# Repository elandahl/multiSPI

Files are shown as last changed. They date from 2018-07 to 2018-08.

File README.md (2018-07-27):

# multiSPI
Multiple SPI Devices on a Raspberry Pi

## Description:

Circuit diagram and software to use multiple (> 2) SPI devices on a Raspberry Pi.  This approach uses a shift register to address a demultiplexer which in turn routes up to eight chip selects.  All devices share the same MISO, MOSI, and SCLK.  The Raspberry Pi chip select CE0 is used for SPI communication to the selected device, whereas chip select CE1 is used for latching the shift register.  The particular SPI devices used in this design for demonstration purposes are four 10 bit, 4 differential channel MCP3008 Analog-to-Digital Converters.  Differential voltage measurement is implemented, although the 4 differential measurements could be replaced with eight single inputs.  Another four SPI devices could be added, and this could be further extended with a second demultiplexer to 16 devices.  An additional shft register could be added after the first for essentially unlimited extension to arbitrary numbers of SPI devices.  This same approach could be extended to other platforms such as a microcontroller.

## Author:

Eric Landahl, elandahl@gmail.com

## Acknowledgements:

Motivation from C.D. Landahl

Concept from Ellie Martin-Eberhardt

Requires use of the [C library for Broadcom BCM 2835 as used in Raspberry Pi](http://www.airspayce.com/mikem/bcm2835/index.html) by Mike McCauley.  The code here is based closely on the bcm2835 example file `spin.c`.

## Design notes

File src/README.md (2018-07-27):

# Directory of source files for multiSPI
## Installation
1. Obtain and install the [bcm2835 library](http://www.airspayce.com/mikem/bcm2835/index.html)
2. Download `MCP3008read.c` and compile with the command `gcc -o MCP3008read MCP3008read.c -l bcm2835`
3. Download `SPIselect.c` and compile with the command `gcc -o SPIselect SPIselect.c -l bcm2835`
## Usage
To select an SPI device:  `sudo ./SPIselect` *num*
  
where *num* is the address 0 - F

For instance, `sudo ./SPIselect 1` should return the statement `Device 1 has been selected`.

To read 4 differential voltages of the selected MCP3008 ADC:  `./MCP3008read`

This will return the hexadecimal readings for each differential pair; see MCP3008 datasheet for details on how to convert this output to a voltage.

Note that the use of `sudo` may not be required in more recent versions of Raspbian. Also note that depending on the Raspbian version, the SPI may need to be configured using `sudo raspi-config`.

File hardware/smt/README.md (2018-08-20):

Surface Mount design for multiSPI

multiple SPI (> 2) SPI devices on Raspberry Pi. In this case, 4x MCP3008 ADCs. 

OSH Park fabrication in process:  https://oshpark.com/shared_projects/mubjyDKl

This version uses surface mount components and has extra outputs (shift register, CEs, and SPI).s

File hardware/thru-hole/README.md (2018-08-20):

# Hardware design files for multiSPI test board

## Contents
Schematic prepared in EAGLE 9.1.0, and using DIP format comonents

Available as .png, .pdf, and EAGLE .sch files

PCB files are now also attached as .brd and well as an image as multiSPI2.pdf

First PCB has been ordered from OSH Park!  [https://oshpark.com/shared_projects/Ye1AAnSY](https://oshpark.com/shared_projects/Ye1AAnSY)

## Hardware used for tests

1. Raspberry Pi Model 3B running Raspbian GNU/Linux 8.0 (jessie)
2. Canakit cobbler breakout 
3. Full size solderless breadboard
4. Shift Register: SN74HC595N
5. Demultiplexer: T74LS138B1
6. ADC (QTY = 2 tested, QTY = 4 in circuit diagram): MCP3008
7. Pullup resistors on multi-chip select lines: (QTY = 2 or 4) approximately 100 kOhm

## Notes
Pin 13 on the 74595 is labeled as "G" on the schematic but appears instead as "~OE" on most datasheets, for "complimentary output enable".  It should be connected to GND for this application.

There is a missing GND on one of the terminal headers.

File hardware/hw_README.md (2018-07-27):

Schematic only so far, prepared in EAGLE 9.1.0
PCB files under preparation

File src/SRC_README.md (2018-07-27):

# Directory of source files for multiSPI
## Installation
1. bcm2835 library
2. multiSPI
## Usage
To select an SPI device:  `./SPIselect` *num*
  
where *num* is the address 0 - F

For instance, `./SPIselect 1` should return the statement `Device 1 has been selected`.

To read 4 differential voltages of the selected MCP3008 ADC:  `./MCP3008read`

This will return the hexadecimal readings for each differential pair; see MCP3008 datasheet for details on how to convert this output to a voltage.

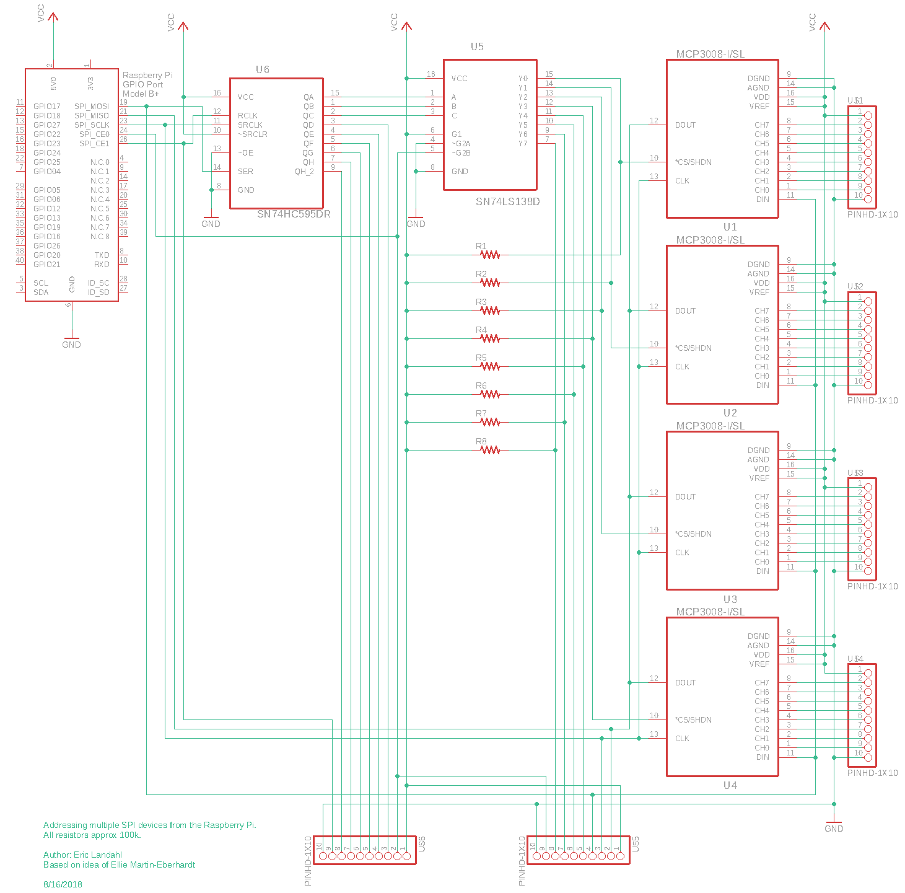
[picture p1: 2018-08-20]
hardware/smt/multiSPI_v21_sch.png

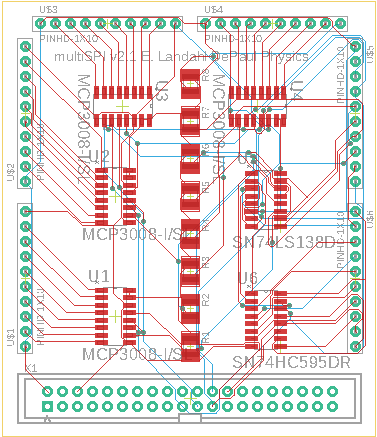
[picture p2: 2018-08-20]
hardware/smt/multiSPI_v21_brd.png

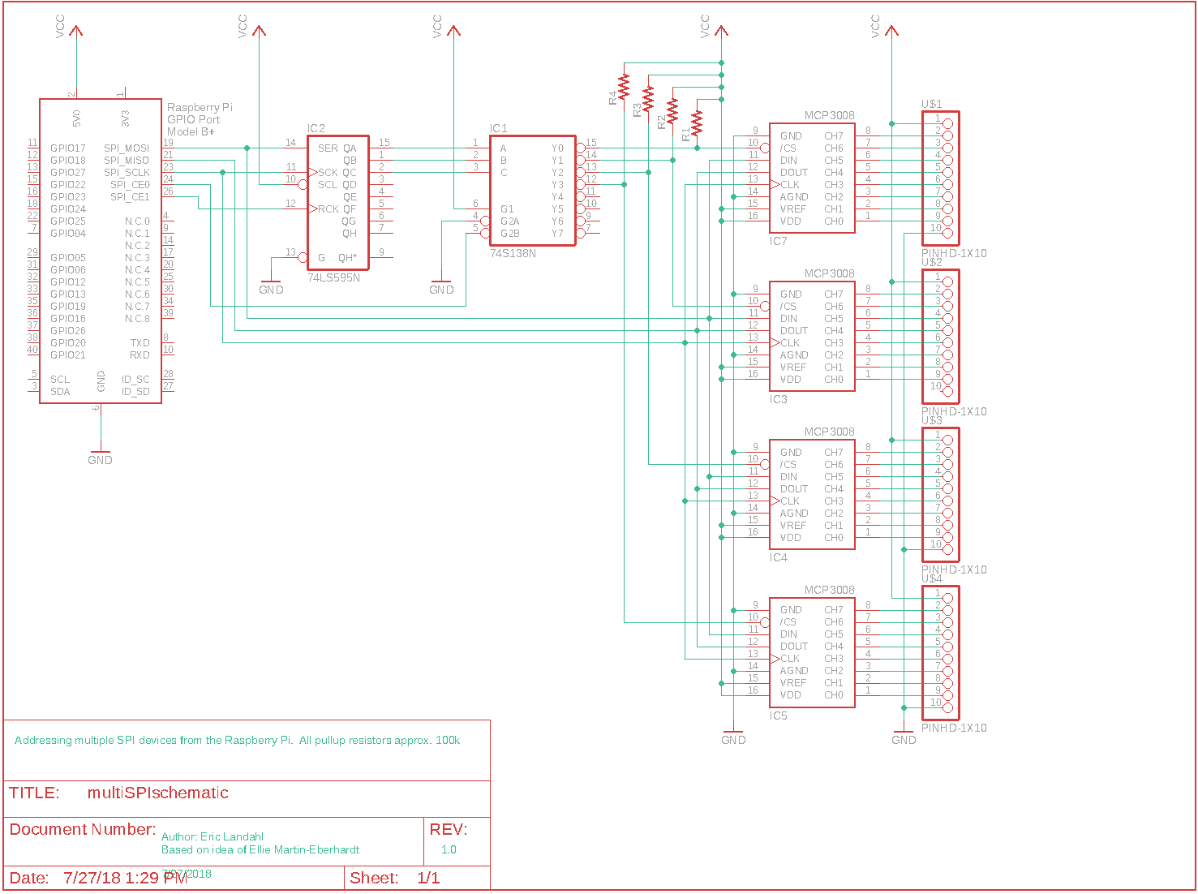
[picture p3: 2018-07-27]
hardware/thru-hole/multiSPIschematic.png

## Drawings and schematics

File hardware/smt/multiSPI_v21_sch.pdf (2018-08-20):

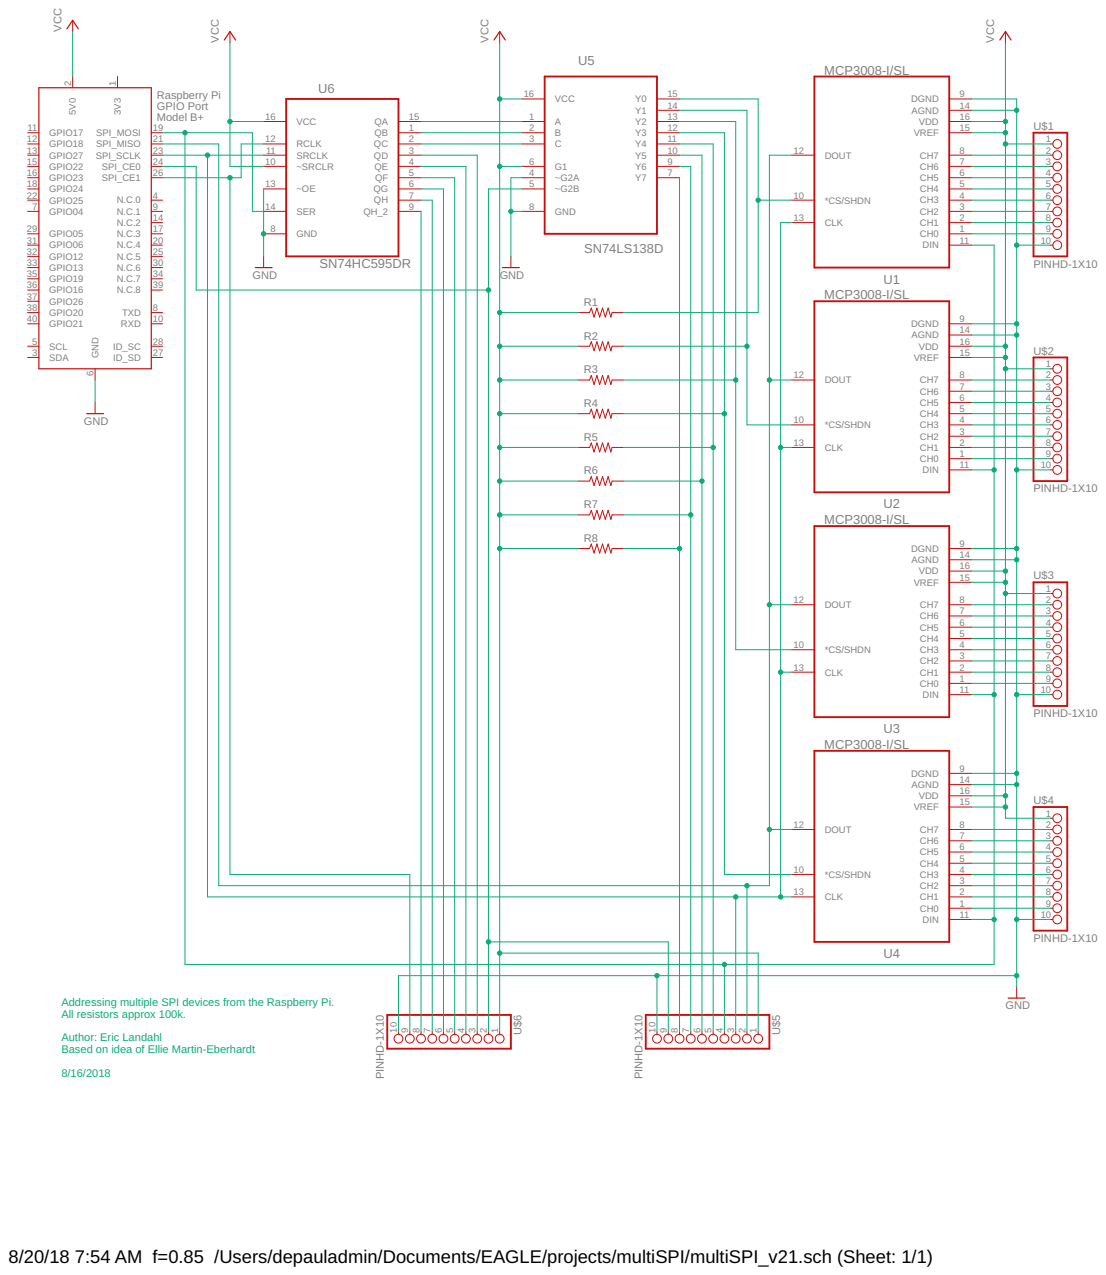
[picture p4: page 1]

Raspberry Pi GPIO Port Model B+

14 DGND
16 AGND
15 VDD

16 AGND 15 VDD

Addressing multiple SPI devices from the Raspberry Pi. All resistors approx 100k. Author: Eric Landahl Based on idea of Ellie Martin-Eberhardt 8/16/2018

8/20/18 7:54 AM f=0.85 /Users/depauladmin/Documents/EAGLE/projects/multiSPI/multiSPI_v21.sch (Sheet: 1/1)

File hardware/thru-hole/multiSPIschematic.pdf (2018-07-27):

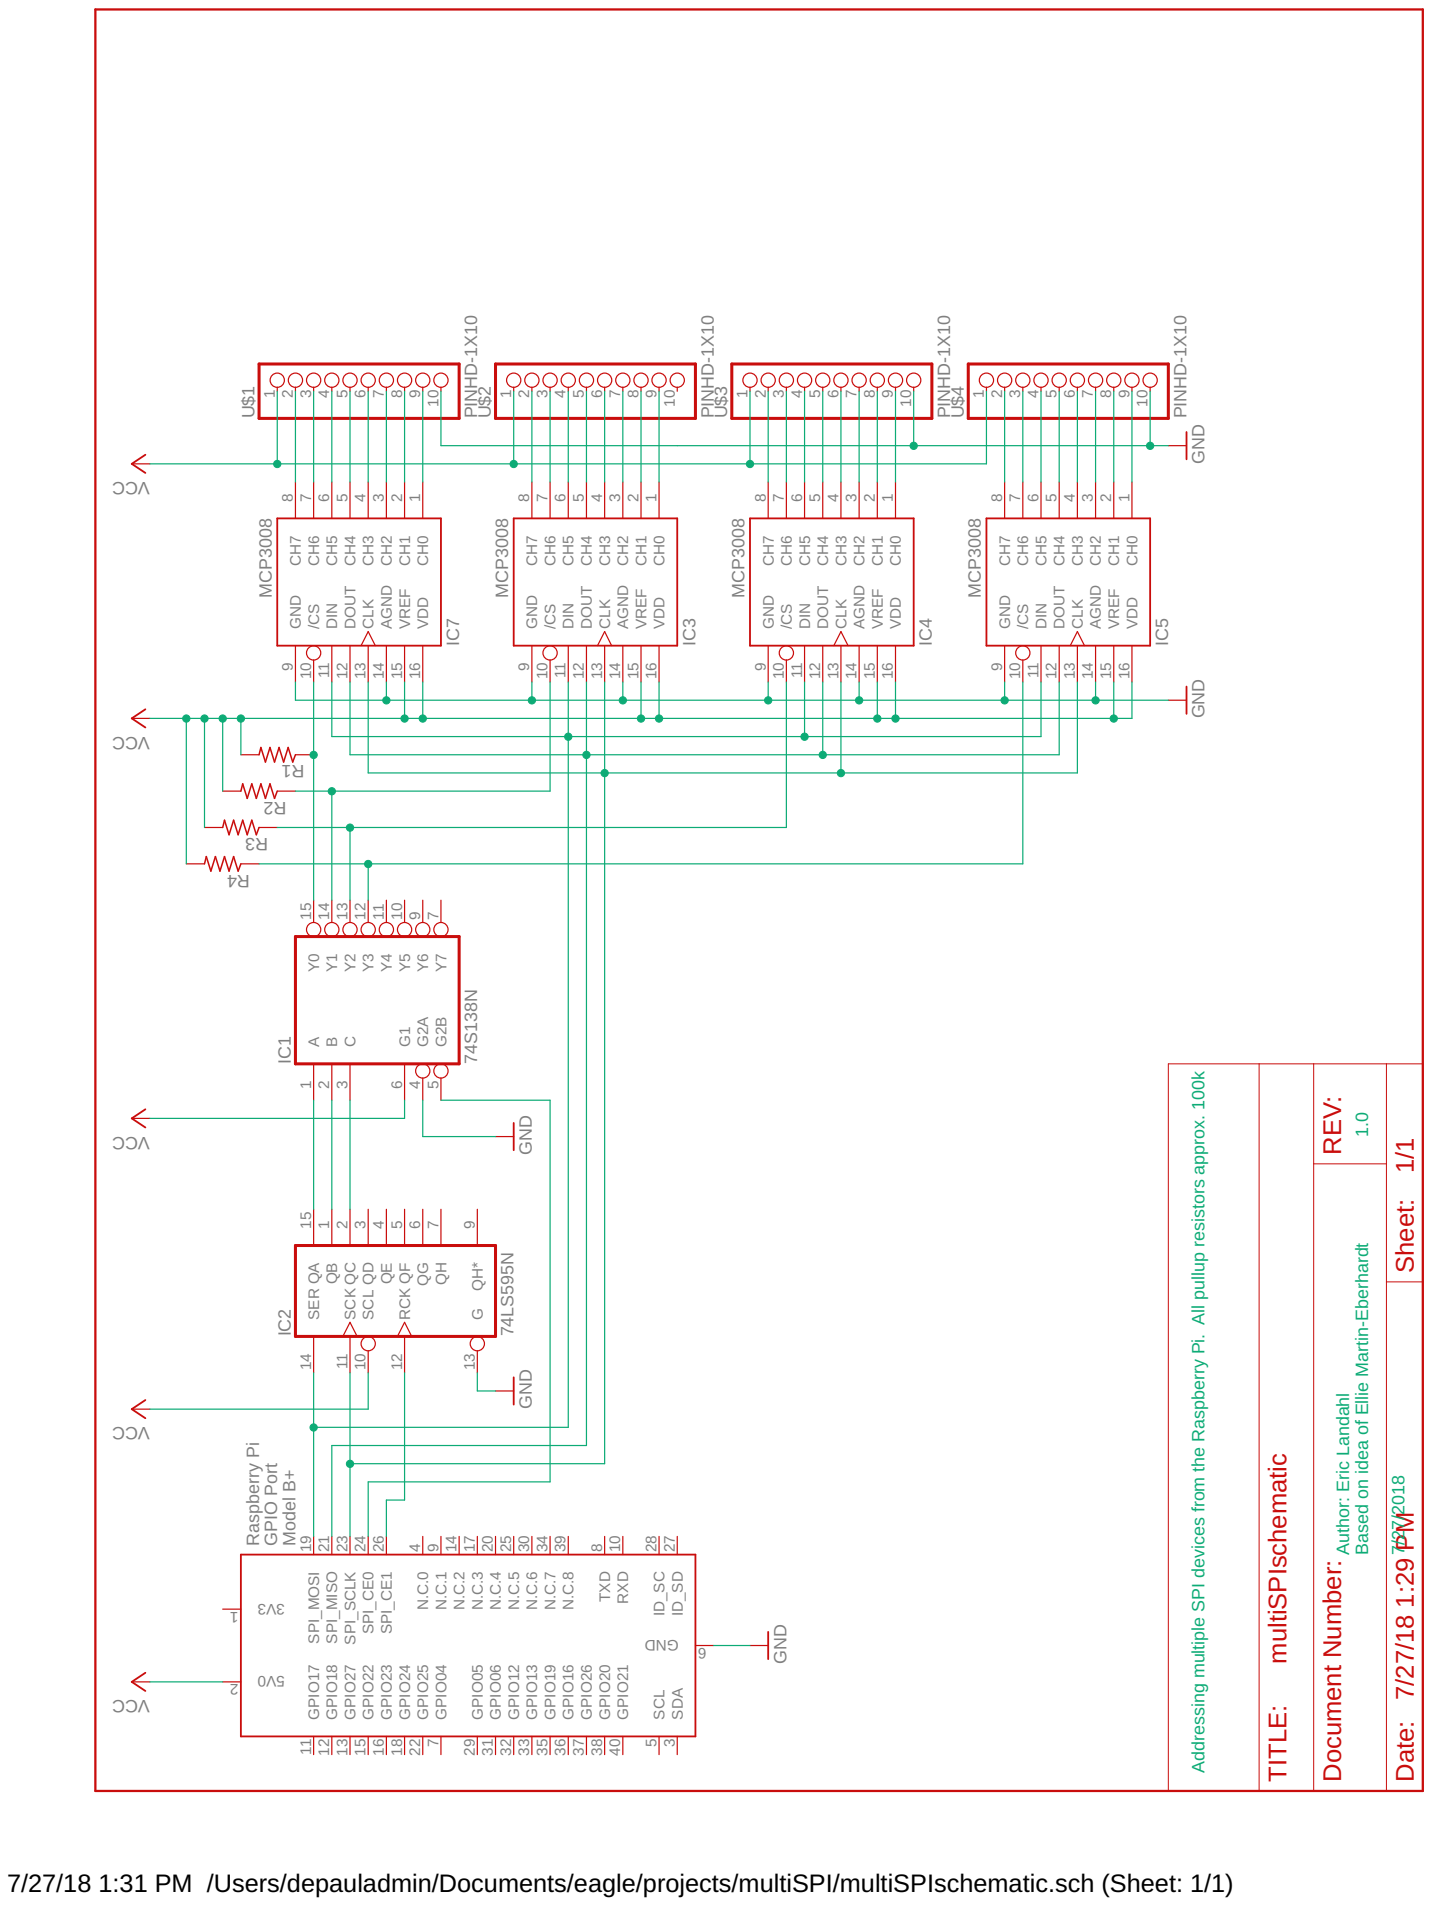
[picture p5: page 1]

Addressing multiple SPI devices from the Raspberry Pi. All pullup resistors approx. 100k Author: Eric Landahl Based on idea of Ellie Martin-Eberhardt 1.0

Raspberry Pi GPIO Port Model B+

7/27/18 1:31 PM /Users/depauladmin/Documents/eagle/projects/multiSPI/multiSPIschematic.sch (Sheet: 1/1)

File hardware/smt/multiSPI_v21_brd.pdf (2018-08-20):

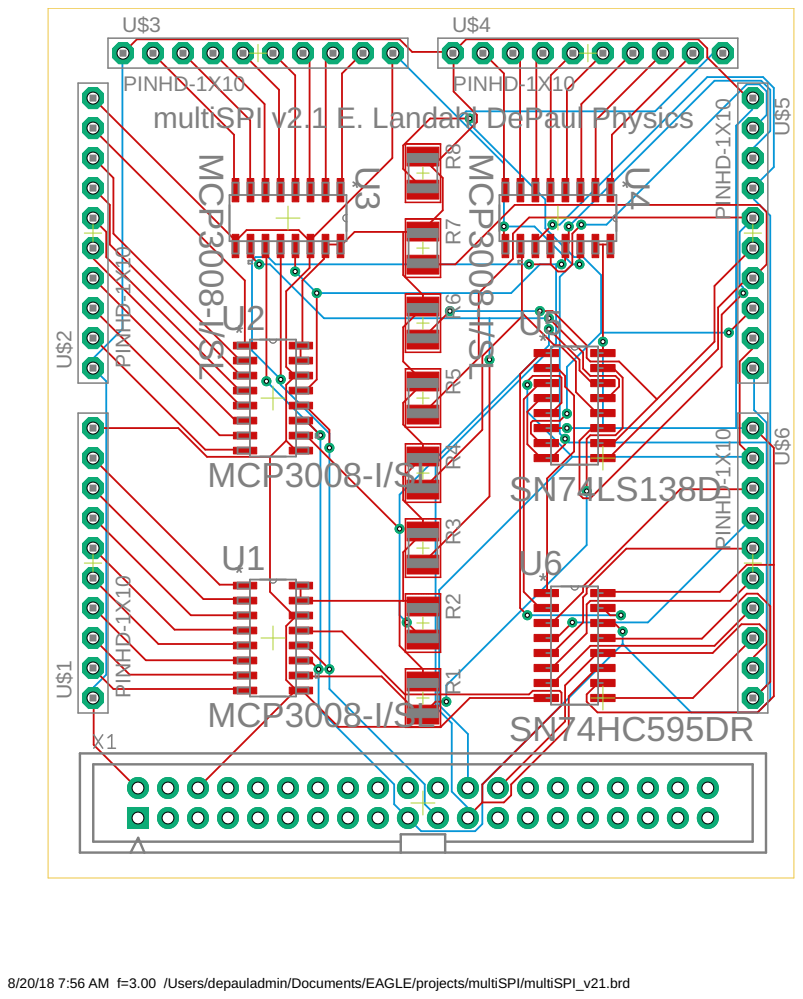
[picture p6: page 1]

multiSPI v2.1 E. Landahl DePaul Physics

8/20/18 7:56 AM f=3.00 /Users/depauladmin/Documents/EAGLE/projects/multiSPI/multiSPI_v21.brd

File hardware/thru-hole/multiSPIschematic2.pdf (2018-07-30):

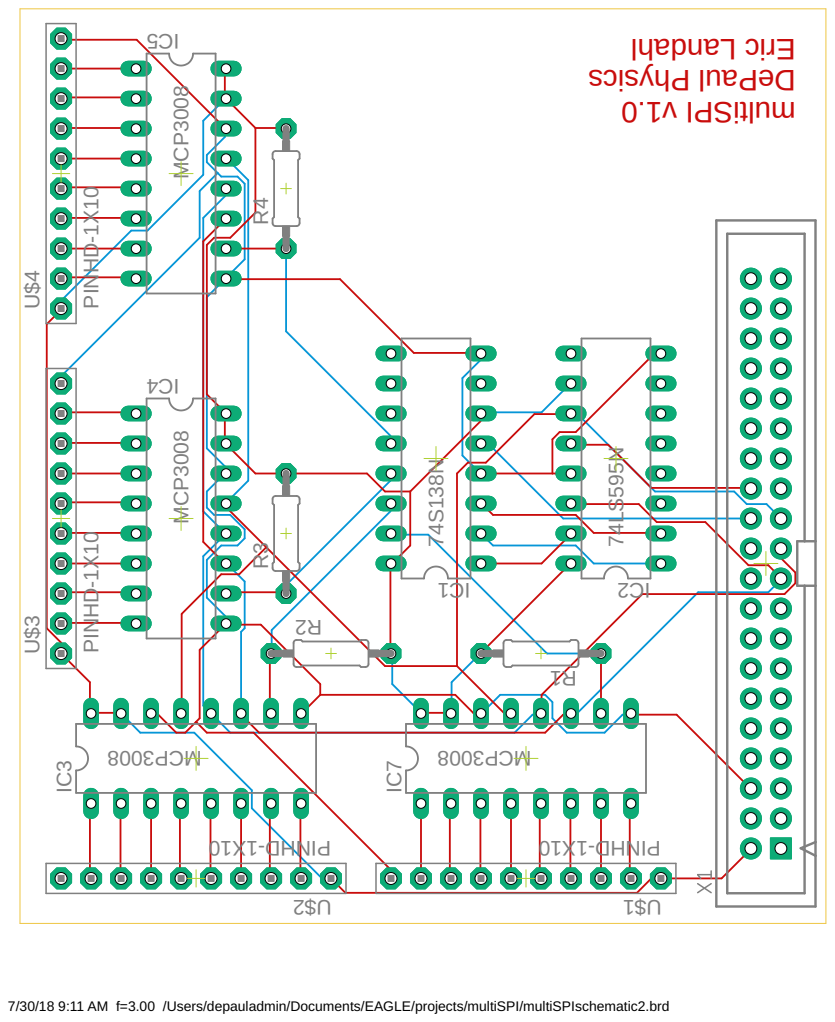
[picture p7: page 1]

7/30/18 9:11 AM f=3.00 /Users/depauladmin/Documents/EAGLE/projects/multiSPI/multiSPIschematic2.brd

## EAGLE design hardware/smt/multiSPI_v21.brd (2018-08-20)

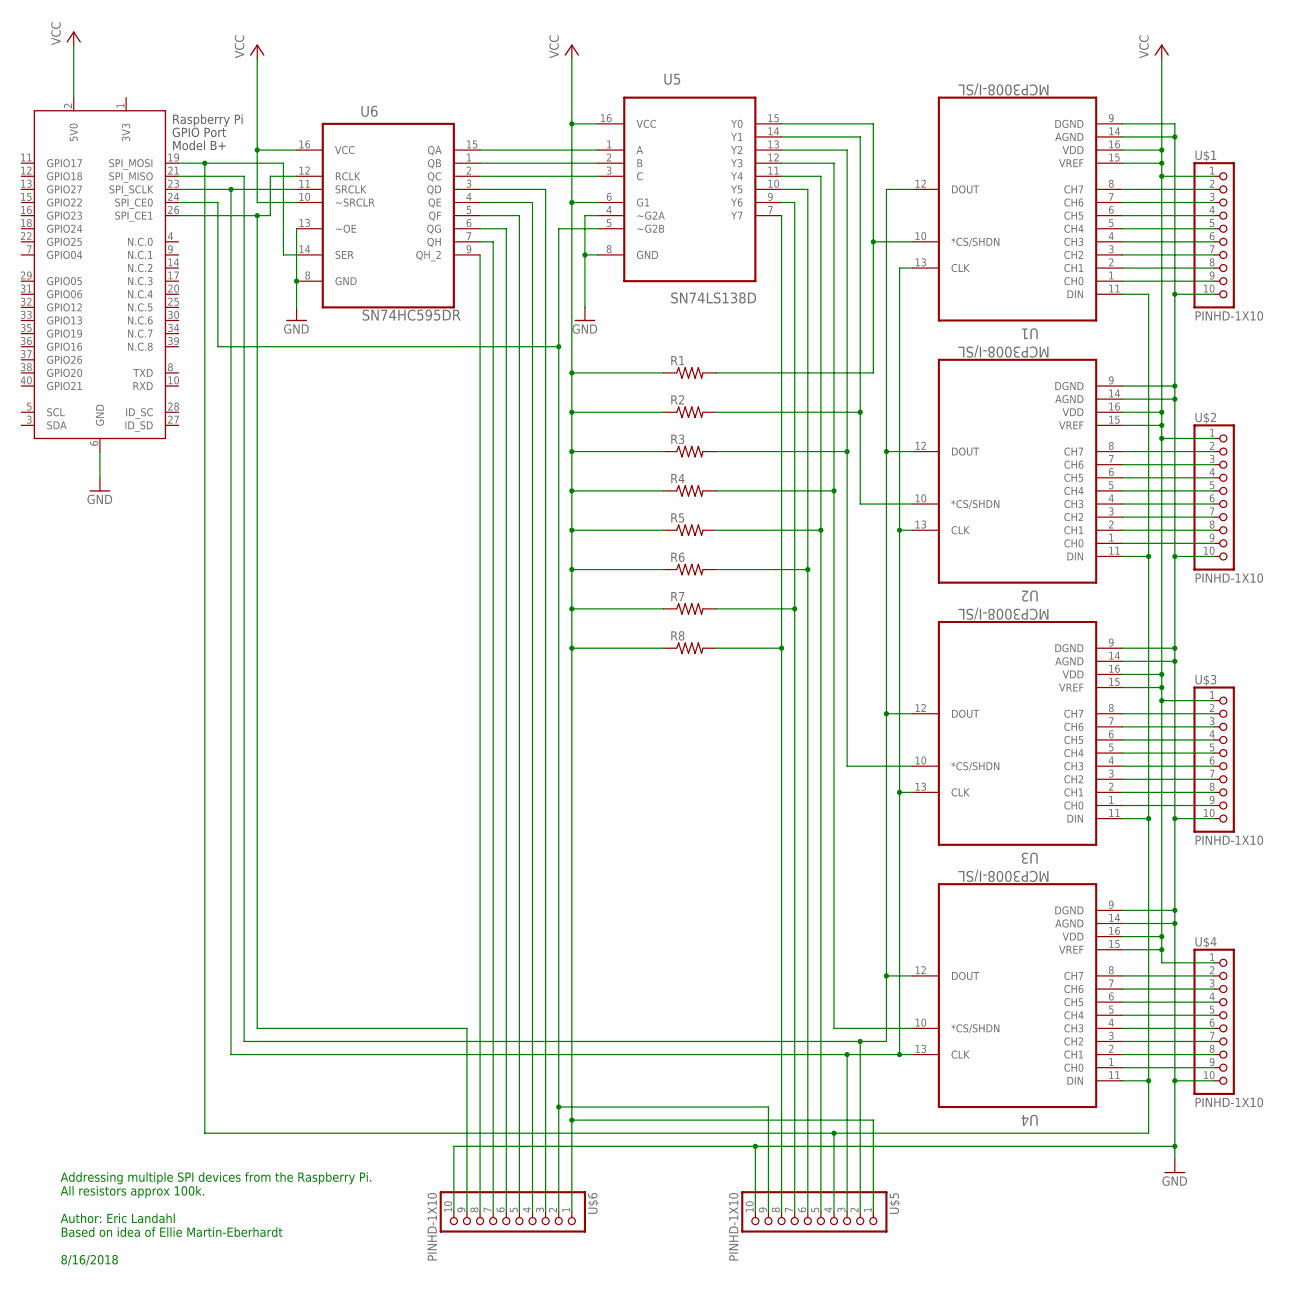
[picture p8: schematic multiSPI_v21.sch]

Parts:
R1, R2, R3, R4, R5, R6, R7, R8: R-US_R1210; R1210
U1, U2, U3, U4: MCP3008-I/SL; SOIC127P600X175-16N
U5: SN74LS138D; SOIC127P600X175-16N
U6: SN74HC595DR; SOIC127P600X175-16N
U$1, U$2, U$3, U$4, U$5, U$6: PINHD-1X10; 1X10-BIG
X1: RASPI_GPIO_B+_BOX

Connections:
3V3: X1.1 (3V3)
GND: U1.9 (DGND), U1.14 (AGND), U2.9 (DGND), U2.14 (AGND), U3.9 (DGND), U3.14 (AGND), U4.9 (DGND), U4.14 (AGND), U5.4 (~G2A), U5.8 (GND), U6.8 (GND), U6.13 (~OE), U$1.10, U$2.10, U$3.10, U$4.10, U$5.10, U$6.10, X1.6 (GND)
unnamed: R8.2, U5.7 (Y7), U$5.8
unnamed: R7.2, U5.9 (Y6), U$5.7
unnamed: R6.2, U5.10 (Y5), U$5.6
unnamed: R4.2, U4.10 (*CS/SHDN), U5.12 (Y3)
unnamed: U1.12 (DOUT), U2.12 (DOUT), U3.12 (DOUT), U4.12 (DOUT), U$5.2, X1.21 (SPI_MISO)
unnamed: R3.2, U3.10 (*CS/SHDN), U5.13 (Y2)
unnamed: R5.2, U5.11 (Y4), U$5.5
unnamed: R2.2, U2.10 (*CS/SHDN), U5.14 (Y1)
unnamed: R1.2, U1.10 (*CS/SHDN), U5.15 (Y0)
unnamed: U1.11 (DIN), U2.11 (DIN), U3.11 (DIN), U4.11 (DIN), U6.14 (SER), U$5.4, X1.19 (SPI_MOSI)
unnamed: U6.12 (RCLK), U$6.9, X1.26 (SPI_CE1)
unnamed: U1.8 (CH7), U$1.2
unnamed: U1.7 (CH6), U$1.3
unnamed: U1.6 (CH5), U$1.4
unnamed: U6.9 (QH_2), U$6.8
unnamed: U1.5 (CH4), U$1.5
unnamed: U1.4 (CH3), U$1.6
unnamed: U1.3 (CH2), U$1.7
unnamed: U1.2 (CH1), U$1.8
unnamed: U1.1 (CH0), U$1.9
unnamed: U2.8 (CH7), U$2.2
unnamed: U2.7 (CH6), U$2.3
unnamed: U2.6 (CH5), U$2.4
unnamed: U2.5 (CH4), U$2.5
unnamed: U2.4 (CH3), U$2.6
unnamed: U2.3 (CH2), U$2.7
unnamed: U2.2 (CH1), U$2.8
unnamed: U2.1 (CH0), U$2.9
unnamed: U3.1 (CH0), U$3.9
unnamed: U3.2 (CH1), U$3.8
unnamed: U3.3 (CH2), U$3.7
unnamed: U3.4 (CH3), U$3.6
unnamed: U3.5 (CH4), U$3.5
unnamed: U3.6 (CH5), U$3.4
unnamed: U3.7 (CH6), U$3.3
unnamed: U3.8 (CH7), U$3.2
unnamed: U4.1 (CH0), U$4.9
unnamed: U4.2 (CH1), U$4.8
unnamed: U4.3 (CH2), U$4.7
unnamed: U4.4 (CH3), U$4.6
unnamed: U4.5 (CH4), U$4.5
unnamed: U4.6 (CH5), U$4.4
unnamed: U4.7 (CH6), U$4.3
unnamed: U4.8 (CH7), U$4.2
unnamed: U1.13 (CLK), U2.13 (CLK), U3.13 (CLK), U4.13 (CLK), U6.11 (SRCLK), U$5.3, X1.23 (SPI_SCLK)
unnamed: U5.5 (~G2B), U$5.9, U$6.2, X1.24 (SPI_CE0)
unnamed: U6.7 (QH), U$6.7
unnamed: U6.6 (QG), U$6.6
unnamed: U6.5 (QF), U$6.5
unnamed: U6.4 (QE), U$6.4
unnamed: U6.3 (QD), U$6.3
unnamed: U5.3 (C), U6.2 (QC)
unnamed: U5.2 (B), U6.1 (QB)
unnamed: U5.1 (A), U6.15 (QA)
VCC: R1.1, R2.1, R3.1, R4.1, R5.1, R6.1, R7.1, R8.1, U1.15 (VREF), U1.16 (VDD), U2.15 (VREF), U2.16 (VDD), U3.15 (VREF), U3.16 (VDD), U4.15 (VREF), U4.16 (VDD), U5.6 (G1), U5.16 (VCC), U6.10 (~SRCLR), U6.16 (VCC), U$1.1, U$2.1, U$3.1, U$4.1, U$5.1, U$6.1, X1.2 (5V0)

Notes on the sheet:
Addressing multiple SPI devices from the Raspberry Pi. All resistors approx 100k. Author: Eric Landahl Based on idea of Ellie Martin-Eberhardt 8/16/2018

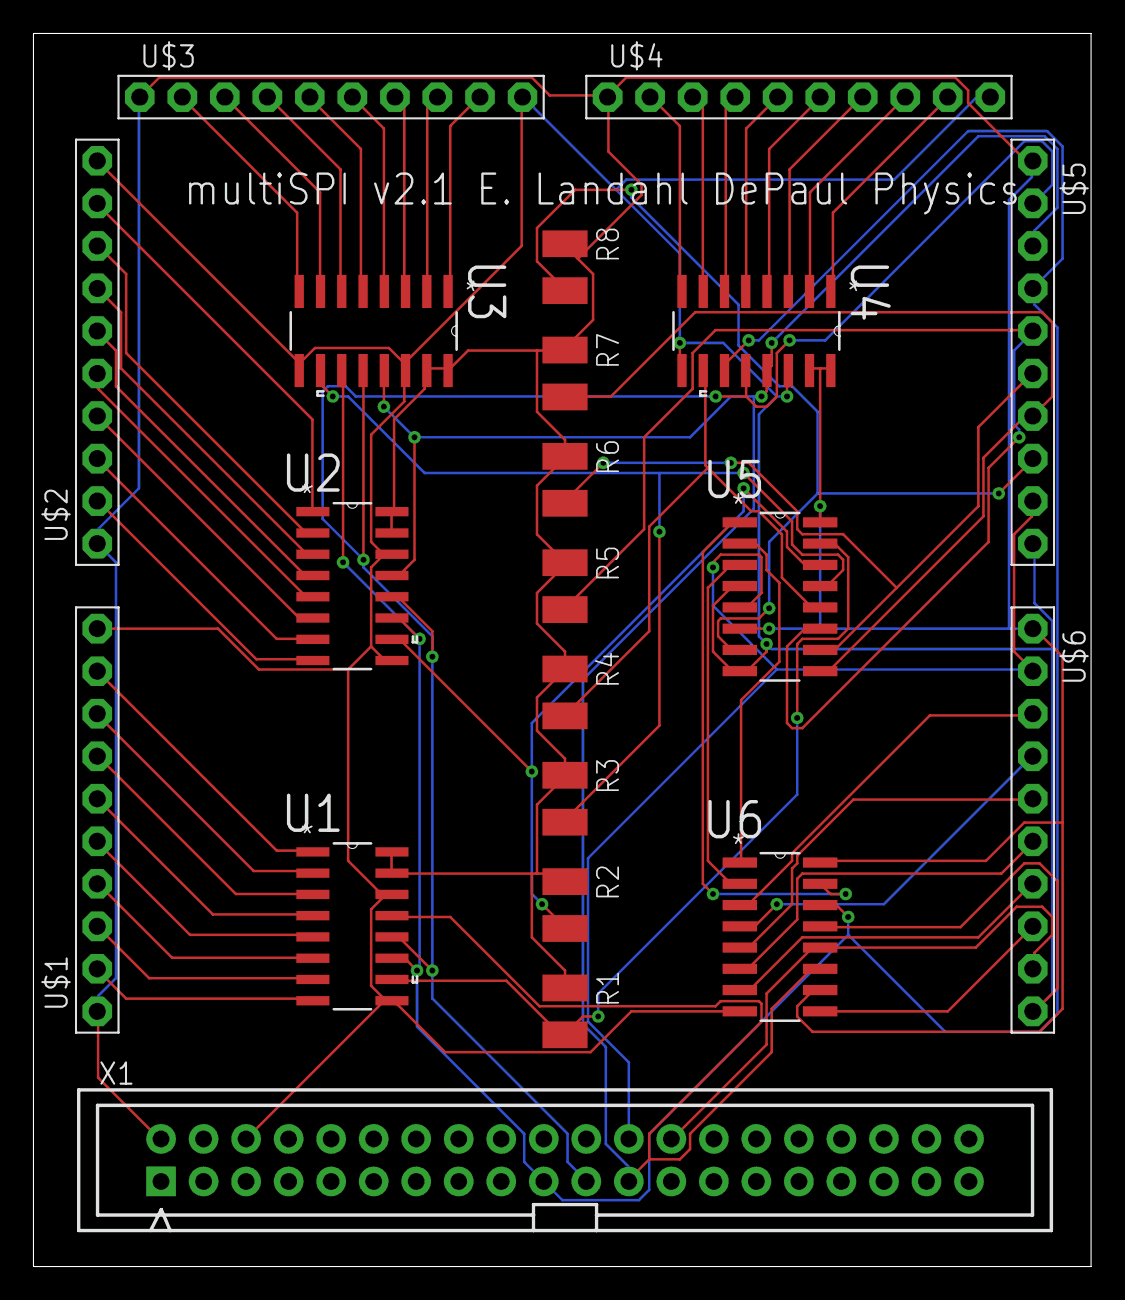
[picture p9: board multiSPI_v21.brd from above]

Board: 2 copper layers, 63.2 x 73.7 mm, 21 parts (0 on the bottom side), 56 nets.

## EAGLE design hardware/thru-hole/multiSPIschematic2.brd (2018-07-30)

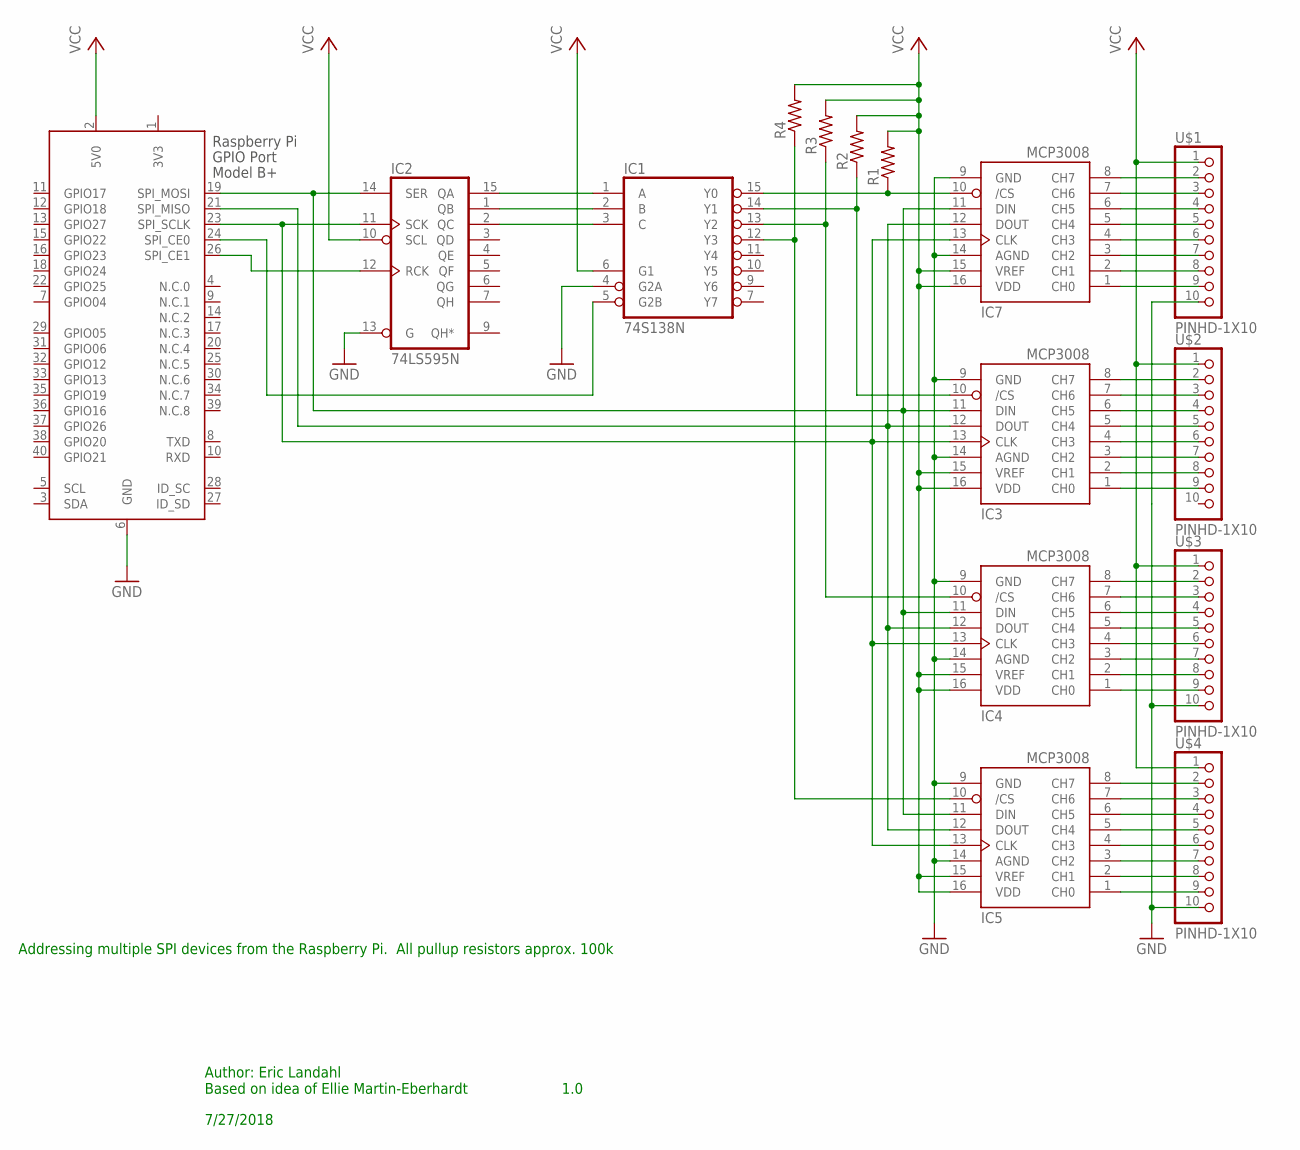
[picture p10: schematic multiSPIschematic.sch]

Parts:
IC1: 74S138N; DIL16
IC2: 74LS595N; DIL16
IC3, IC4, IC5, IC7: MCP3008; DIL16
R1, R2, R3, R4: R-US_0207/10; 0207/10
U$1, U$2, U$3, U$4: PINHD-1X10; 1X10-BIG
X1: RASPI_GPIO_B+_BOX

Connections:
3V3: X1.1 (3V3)
GND: IC1.4 (G2A), IC1.8 (GND), IC2.8 (GND), IC2.13 (G), IC3.9 (GND), IC3.14 (AGND), IC4.9 (GND), IC4.14 (AGND), IC5.9 (GND), IC5.14 (AGND), IC7.9 (GND), IC7.14 (AGND), U$1.10, U$3.10, U$4.10, X1.6 (GND)
unnamed: IC1.1 (A), IC2.15 (QA)
unnamed: IC1.2 (B), IC2.1 (QB)
unnamed: IC1.3 (C), IC2.2 (QC)
unnamed: IC2.11 (SCK), IC3.13 (CLK), IC4.13 (CLK), IC5.13 (CLK), IC7.13 (CLK), X1.23 (SPI_SCLK)
unnamed: IC3.12 (DOUT), IC4.12 (DOUT), IC5.12 (DOUT), IC7.12 (DOUT), X1.21 (SPI_MISO)
unnamed: IC1.15 (Y0), IC7.10 (/CS), R1.1
unnamed: IC2.14 (SER), IC3.11 (DIN), IC4.11 (DIN), IC5.11 (DIN), IC7.11 (DIN), X1.19 (SPI_MOSI)
unnamed: IC1.13 (Y2), IC4.10 (/CS), R3.1
unnamed: IC1.14 (Y1), IC3.10 (/CS), R2.1
unnamed: IC1.12 (Y3), IC5.10 (/CS), R4.1
unnamed: IC2.12 (RCK), X1.26 (SPI_CE1)
unnamed: IC7.8 (CH7), U$1.2
unnamed: IC7.7 (CH6), U$1.3
unnamed: IC7.6 (CH5), U$1.4
unnamed: IC1.5 (G2B), X1.24 (SPI_CE0)
unnamed: IC7.5 (CH4), U$1.5
unnamed: IC7.4 (CH3), U$1.6
unnamed: IC7.3 (CH2), U$1.7
unnamed: IC7.2 (CH1), U$1.8
unnamed: IC7.1 (CH0), U$1.9
unnamed: IC3.8 (CH7), U$2.2
unnamed: IC3.7 (CH6), U$2.3
unnamed: IC3.6 (CH5), U$2.4
unnamed: IC3.5 (CH4), U$2.5
unnamed: IC3.4 (CH3), U$2.6
unnamed: IC3.3 (CH2), U$2.7
unnamed: IC3.2 (CH1), U$2.8
unnamed: IC3.1 (CH0), U$2.9
unnamed: IC4.1 (CH0), U$3.9
unnamed: IC4.2 (CH1), U$3.8
unnamed: IC4.3 (CH2), U$3.7
unnamed: IC4.4 (CH3), U$3.6
unnamed: IC4.5 (CH4), U$3.5
unnamed: IC4.6 (CH5), U$3.4
unnamed: IC4.7 (CH6), U$3.3
unnamed: IC4.8 (CH7), U$3.2
unnamed: IC5.1 (CH0), U$4.9
unnamed: IC5.2 (CH1), U$4.8
unnamed: IC5.3 (CH2), U$4.7
unnamed: IC5.4 (CH3), U$4.6
unnamed: IC5.5 (CH4), U$4.5
unnamed: IC5.6 (CH5), U$4.4
unnamed: IC5.7 (CH6), U$4.3
unnamed: IC5.8 (CH7), U$4.2
VCC: IC1.6 (G1), IC1.16 (VCC), IC2.10 (SCL), IC2.16 (VCC), IC3.15 (VREF), IC3.16 (VDD), IC4.15 (VREF), IC4.16 (VDD), IC5.15 (VREF), IC5.16 (VDD), IC7.15 (VREF), IC7.16 (VDD), R1.2, R2.2, R3.2, R4.2, U$1.1, U$2.1, U$3.1, U$4.1, X1.2 (5V0)

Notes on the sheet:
Addressing multiple SPI devices from the Raspberry Pi. All pullup resistors approx. 100k
Author: Eric Landahl Based on idea of Ellie Martin-Eberhardt
1.0
7/27/2018

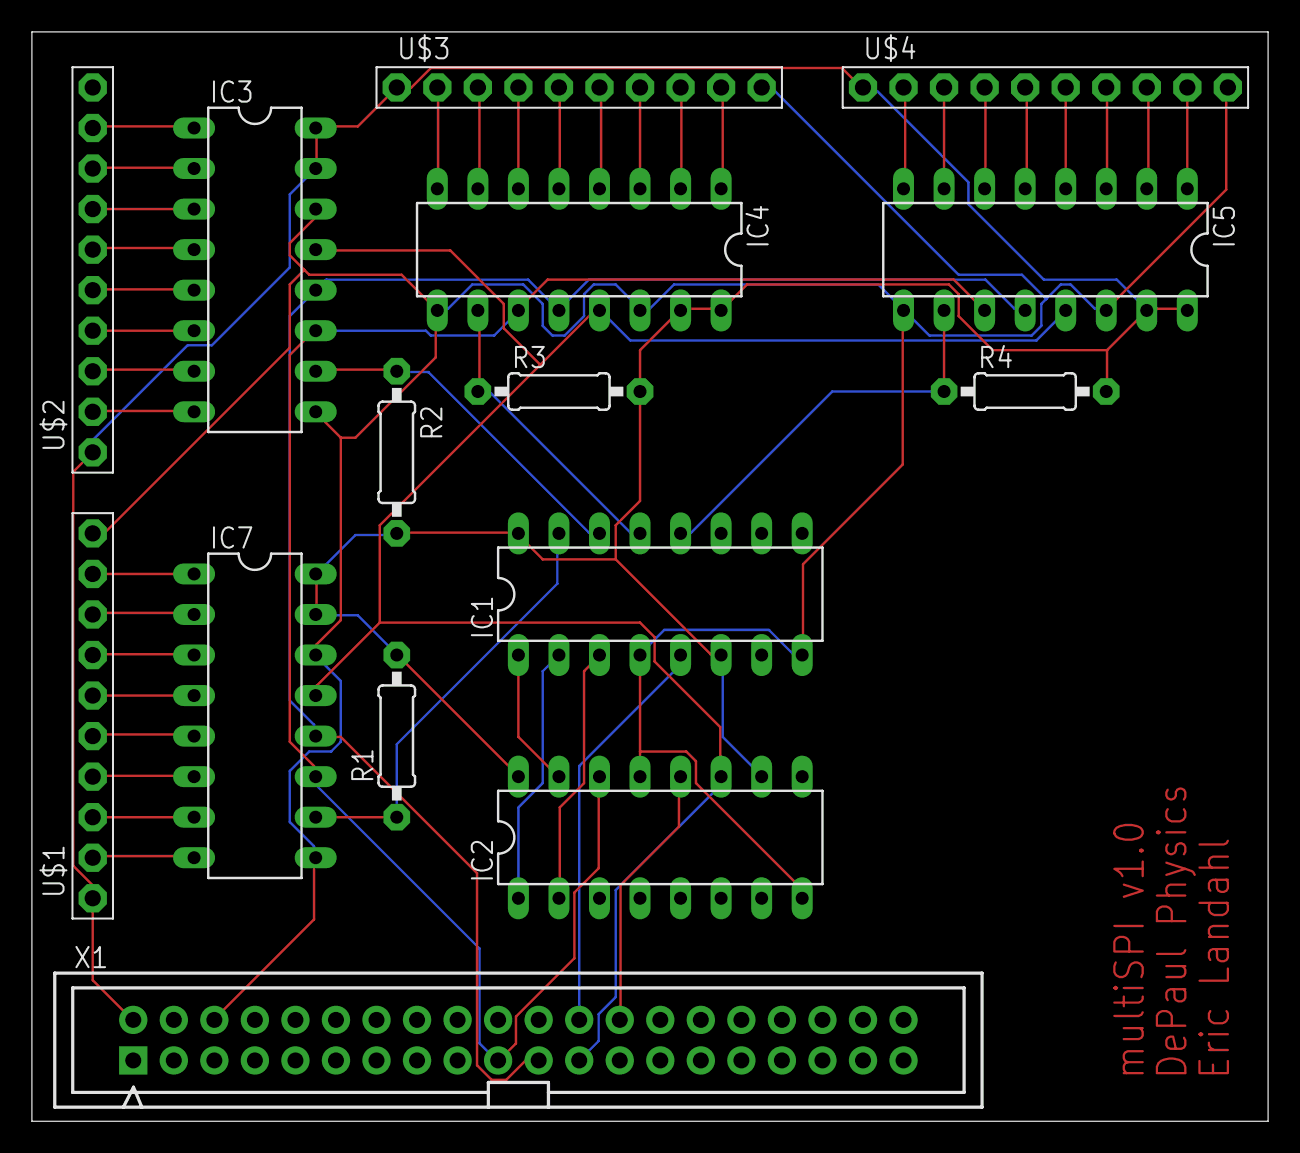
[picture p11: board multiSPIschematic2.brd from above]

Board: 2 copper layers, 77.5 x 68.2 mm, 15 parts (0 on the bottom side), 46 nets.

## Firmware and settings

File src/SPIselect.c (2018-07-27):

// SPIselect.c
//
// By Eric Landahl, 7/25/2018
// Program to select a particular SPI device using a shift register and DeMux
// Note that the Shift Register Chip Select should be connected to CE1
// And the DeMux should be connected to CE0
//
// After installing bcm2835, you can build this 
// with something like:
// gcc -o SPIselect SPIselect.c -l bcm2835
// sudo ./SPIselect 2
// where in this case 2 is the device number, currently 0 - F
//
// Adapted from spin.c by Mike McCauley
// See http://www.airspayce.com/mikem/bcm2835/index.html  
// Copyright (C) 2012 Mike McCauley
// $Id: RF22.h,v 1.21 2012/05/30 01:51:25 mikem Exp $

#include <bcm2835.h>
#include <stdio.h>

int main(int argc, char **argv)
{
    // If you call this, it will not actually access the GPIO
// Use for testing
//        bcm2835_set_debug(1);
    
    if (!bcm2835_init())
    {
      printf("bcm2835_init failed. Are you running as root??\n");
      return 1;
    }

    if (!bcm2835_spi_begin())
    {
      printf("bcm2835_spi_begin failed. Are you running as root??\n");
      return 1;
    }
    bcm2835_spi_begin();
    bcm2835_spi_setBitOrder(BCM2835_SPI_BIT_ORDER_MSBFIRST);      // The default
    bcm2835_spi_setDataMode(BCM2835_SPI_MODE0);                   // The default
    bcm2835_spi_setClockDivider(BCM2835_SPI_CLOCK_DIVIDER_65536); // The default
    bcm2835_spi_chipSelect(BCM2835_SPI_CS1);                      // The default
    bcm2835_spi_setChipSelectPolarity(BCM2835_SPI_CS1, LOW);      // the default
    
    // Send a some bytes to the slave and simultaneously read 
    // some bytes back from the slave
    // Most SPI devices expect one or 2 bytes of command, after which they will send back
    // some data. In such a case you will have the command bytes first in the buffer,
    // followed by as many 0 bytes as you expect returned data bytes. After the transfer, you 
    // Can the read the reply bytes from the buffer.
    // If you tie MISO to MOSI, you should read back what was sent.

    // Select channel 0
    if( *argv[1] == '0' )
    {
      char buf[]={ 0x00 };
      bcm2835_spi_transfern(buf, 1);
      printf("Device 0 has been selected\n");
    }

    // Select channel 1
    if( *argv[1] == '1' )
    {
      char buf[]={ 0x01 };
      bcm2835_spi_transfern(buf, 1);
      printf("Device 1 has been selected\n");
    }

    // Select channel 2
    if( *argv[1] == '2' )
    {
      char buf[]={ 0x02 };
      bcm2835_spi_transfern(buf, 1);
      printf("Device 2 has been selected\n");
     }

    // Select channel 3
    if( *argv[1] == '3' )
    {
      char buf[]={ 0x03 };
      bcm2835_spi_transfern(buf, 1);
      printf("Device 3 has been selected\n");
     }

    // Select channel 4
    if( *argv[1] == '4' )
    {
      char buf[]={ 0x04 };
      bcm2835_spi_transfern(buf, 1);
      printf("Device 4 has been selected\n");
     }

    // Select channel 5
    if( *argv[1] == '5' )
    {
      char buf[]={ 0x05 };
      bcm2835_spi_transfern(buf, 1);
      printf("Device 5 has been selected\n");
     }

    // Select channel 6
    if( *argv[1] == '6' )
    {
      char buf[]={ 0x06 };
      bcm2835_spi_transfern(buf, 1);
      printf("Device 6 has been selected\n");
     }

    // Select channel 7
    if( *argv[1] == '7' )
    {
      char buf[]={ 0x07 };
      bcm2835_spi_transfern(buf, 1);
      printf("Device 7 has been selected\n");
     }

    // Select channel 9
    if( *argv[1] == '8' )
    {
      char buf[]={ 0x08 };
      bcm2835_spi_transfern(buf, 1);
      printf("Device 8 has been selected\n");
     }

    // Select channel 9
    if( *argv[1] == '9' )
    {
      char buf[]={ 0x09 };
      bcm2835_spi_transfern(buf, 1);
      printf("Device 9 has been selected\n");
     }

    // Select channel 10
    if( *argv[1] == 'A' )
    {
      char buf[]={ 0x0A };
      bcm2835_spi_transfern(buf, 1);
      printf("Device 10 has been selected\n");
     }

    // Select channel 11
    if( *argv[1] == 'B' )
    {
      char buf[]={ 0x0B };
      bcm2835_spi_transfern(buf, 1);
      printf("Device 11 has been selected\n");
     }

    // Select channel 12
    if( *argv[1] == 'C' )
    {
      char buf[]={ 0x0C };
      bcm2835_spi_transfern(buf, 1);
      printf("Device 12 has been selected\n");
     }

    // Select channel 13
    if( *argv[1] == 'D' )
    {
      char buf[]={ 0x0D };
      bcm2835_spi_transfern(buf, 1);
      printf("Device 13 has been selected\n");
     }

    // Select channel 14
    if( *argv[1] == 'E' )
    {
      char buf[]={ 0x0E };
      bcm2835_spi_transfern(buf, 1);
      printf("Device 14 has been selected\n");
     }

    // Select channel 15
    if( *argv[1] == 'F' )
    {
      char buf[]={ 0x0F };
      bcm2835_spi_transfern(buf, 1);
      printf("Device 15 has been selected\n");
     }

    bcm2835_spi_end();
    bcm2835_close();
    return 0;
}

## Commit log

2018-07-27 added note on 74595 Pin 13
2018-07-27 photo of test board with 2x ADCs
2018-07-30 EAGLE .brd file for making PCB
    submitted to OSH Park July 30, 2018
    [multiSPIschematic2.brd]
2018-07-30 routed result for PCB file
2018-07-30 PCB Board files added
2018-08-20 new folder for thru-hole version
2018-08-20 Add files via upload
    thru-hold hardware files
    [multiSPIschematic.sch, multiSPIschematic2.brd]
2018-08-20 create folder for surface mount design
2018-08-20 create new folder for surface mount design
